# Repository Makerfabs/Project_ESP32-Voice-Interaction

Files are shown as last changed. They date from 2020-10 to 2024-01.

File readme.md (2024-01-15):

# ESP32 Voice Interaction

```c++
/*
Version:		V1.3
Author:			Vincent
Create Date:	2020/10/16

Note:
		2020/12/24 v1.3: Update readme.
		v1.2 Add Interphone example.
		v1.1 Add Record & Play example.
		
*/
```

[toc]

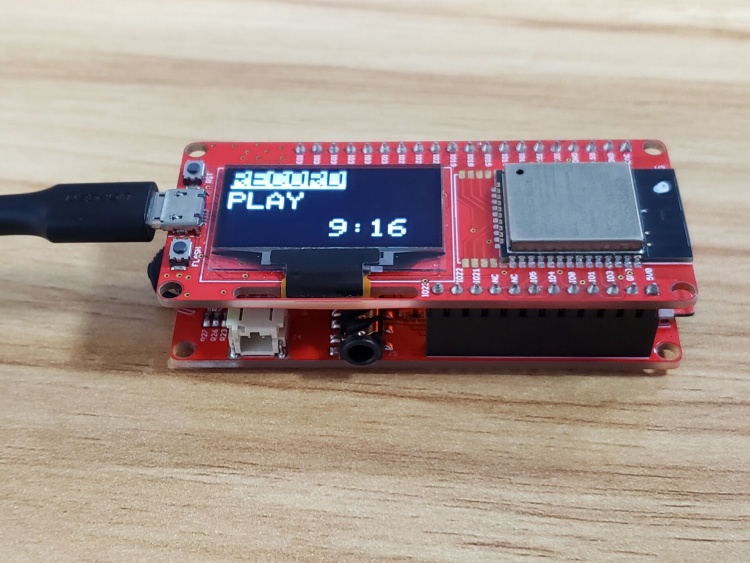
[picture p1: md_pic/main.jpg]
main


# Makerfabs

[Makerfabs home page](https://www.makerfabs.com/)

[Makerfabs Wiki](https://makerfabs.com/wiki/index.php?title=Main_Page)

# ESP32 Voice Interaction Hat

## Intruduce

Product Link ：[Voice Interaction Hat for Makepython](https://www.makerfabs.com/voice-interaction-hat-for-makepython.html) 

Wiki Link :  [Voice_Interaction_Hat_for_MakePython](https://wiki.makerfabs.com/Voice_Interaction_Hat_for_MaESP_ESP32.html) 

ESP32 Voice Interaction is an extended version with speakers and mics. The audio IC is WM8960. It has a button, SD card slot and a headphone jack.  It is convenient to produce MP3, interphone, recording pen and other items. 

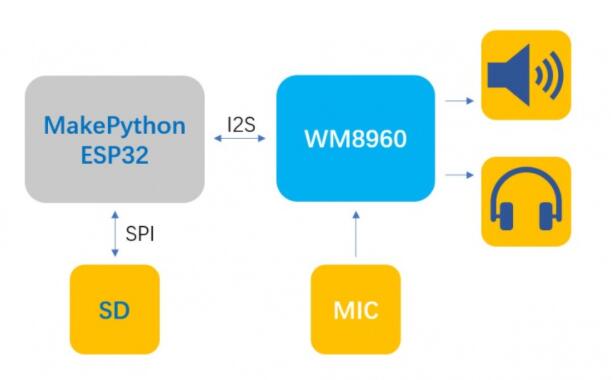
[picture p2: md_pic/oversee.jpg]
oversee


The two functions of recording pen and walkie-talkie are realized. The recorder pen provides a simple menu for selecting play and recording. A UDP walkie-talkie can talk to any device under the same WIFI.

## Feature

- Micro SD card slot on board.

### Front:

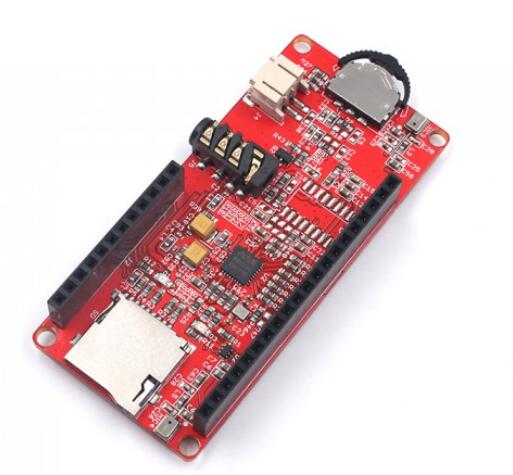
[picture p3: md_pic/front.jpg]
front


### Back:
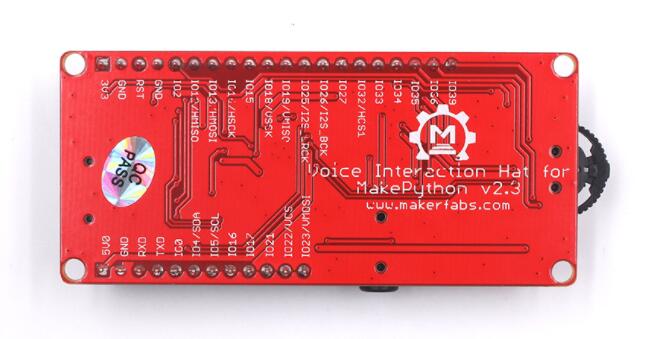
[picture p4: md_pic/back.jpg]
back


# Example

## Equipment list

- [MakePython ESP32](https://www.makerfabs.com/open-hardware/maboards/maesp.html)
- [MakaPython Voice Interaction Hat](https://www.makerfabs.com/voice-interaction-hat-for-makepython.html)
- Micro SD card (Part of the project)

## Compiler Options

**If you have any questions，such as how to install the development board, how to download the code, how to install the library. Please refer to :[Makerfabs_FAQ](https://github.com/Makerfabs/Makerfabs_FAQ)**

- Install board : ESP32 .
- Install library : Adafruit_GFX library.
- Install library : Adafruit SSD1306.

- Insert a Micro SD card into ESP32 Touch Camera.
- Upload codes, select "ESP32 Wrover Module" and "Huge APP"

## Example List

### ESP32_Record_Play
A recorder with a simple menu.

- Insert SD card.
- Upload code to ESP32.
- Restart ESP32.

### ESP32_Interphone
UDP protocol LAN walkie-talkie.

- Prepare two or more ESP32 and Voice Hat.
- Set WIFI ssid and password.
- Upload code to ESP32.
- Restart ESP32.
- Press the left button to speak, and others will play.

### wav_play
Test code, don't use. It can play wav file, but need a specific format.

### record
Record 5 second sound and playback.
- Insert SD card.
- Upload code to ESP32.
- Restart ESP32.
- Press the left button to start recording, recording will end at 5S.
- After the recording is over, the player will play the recording.

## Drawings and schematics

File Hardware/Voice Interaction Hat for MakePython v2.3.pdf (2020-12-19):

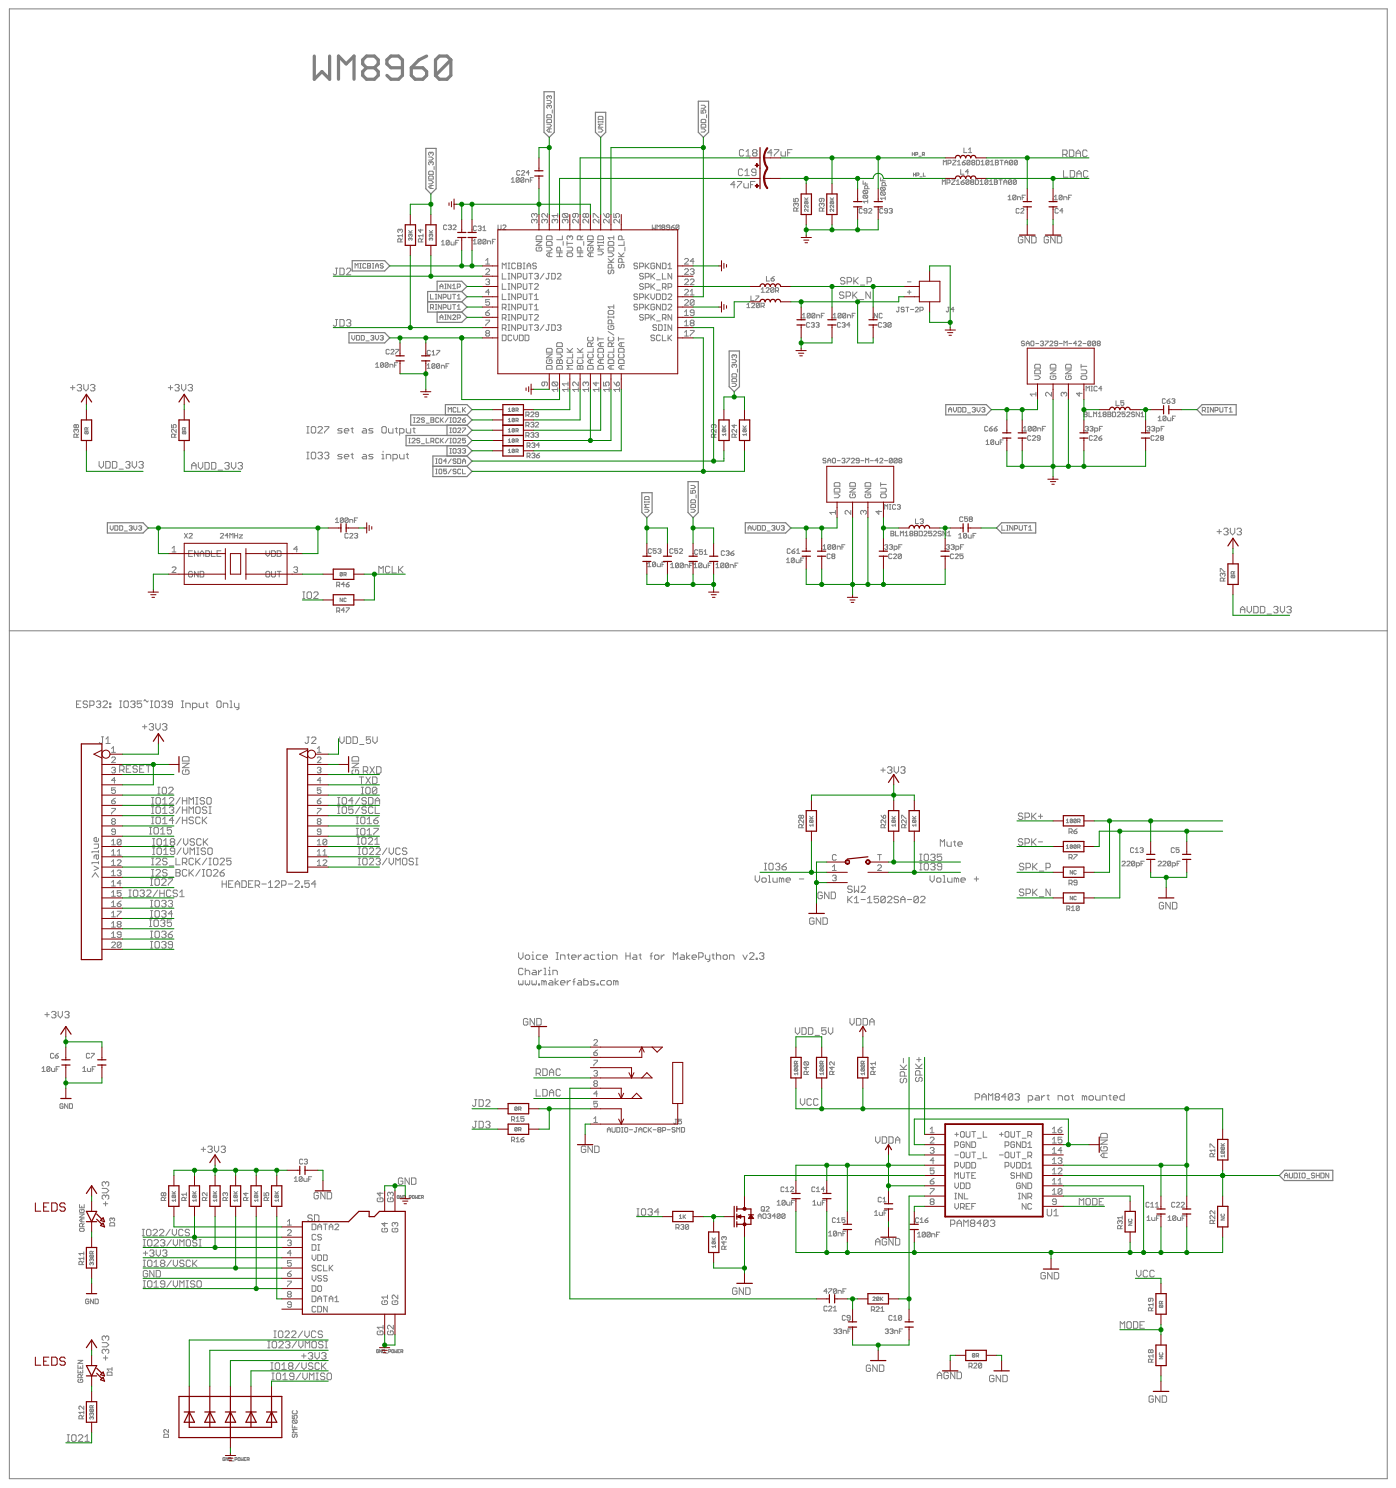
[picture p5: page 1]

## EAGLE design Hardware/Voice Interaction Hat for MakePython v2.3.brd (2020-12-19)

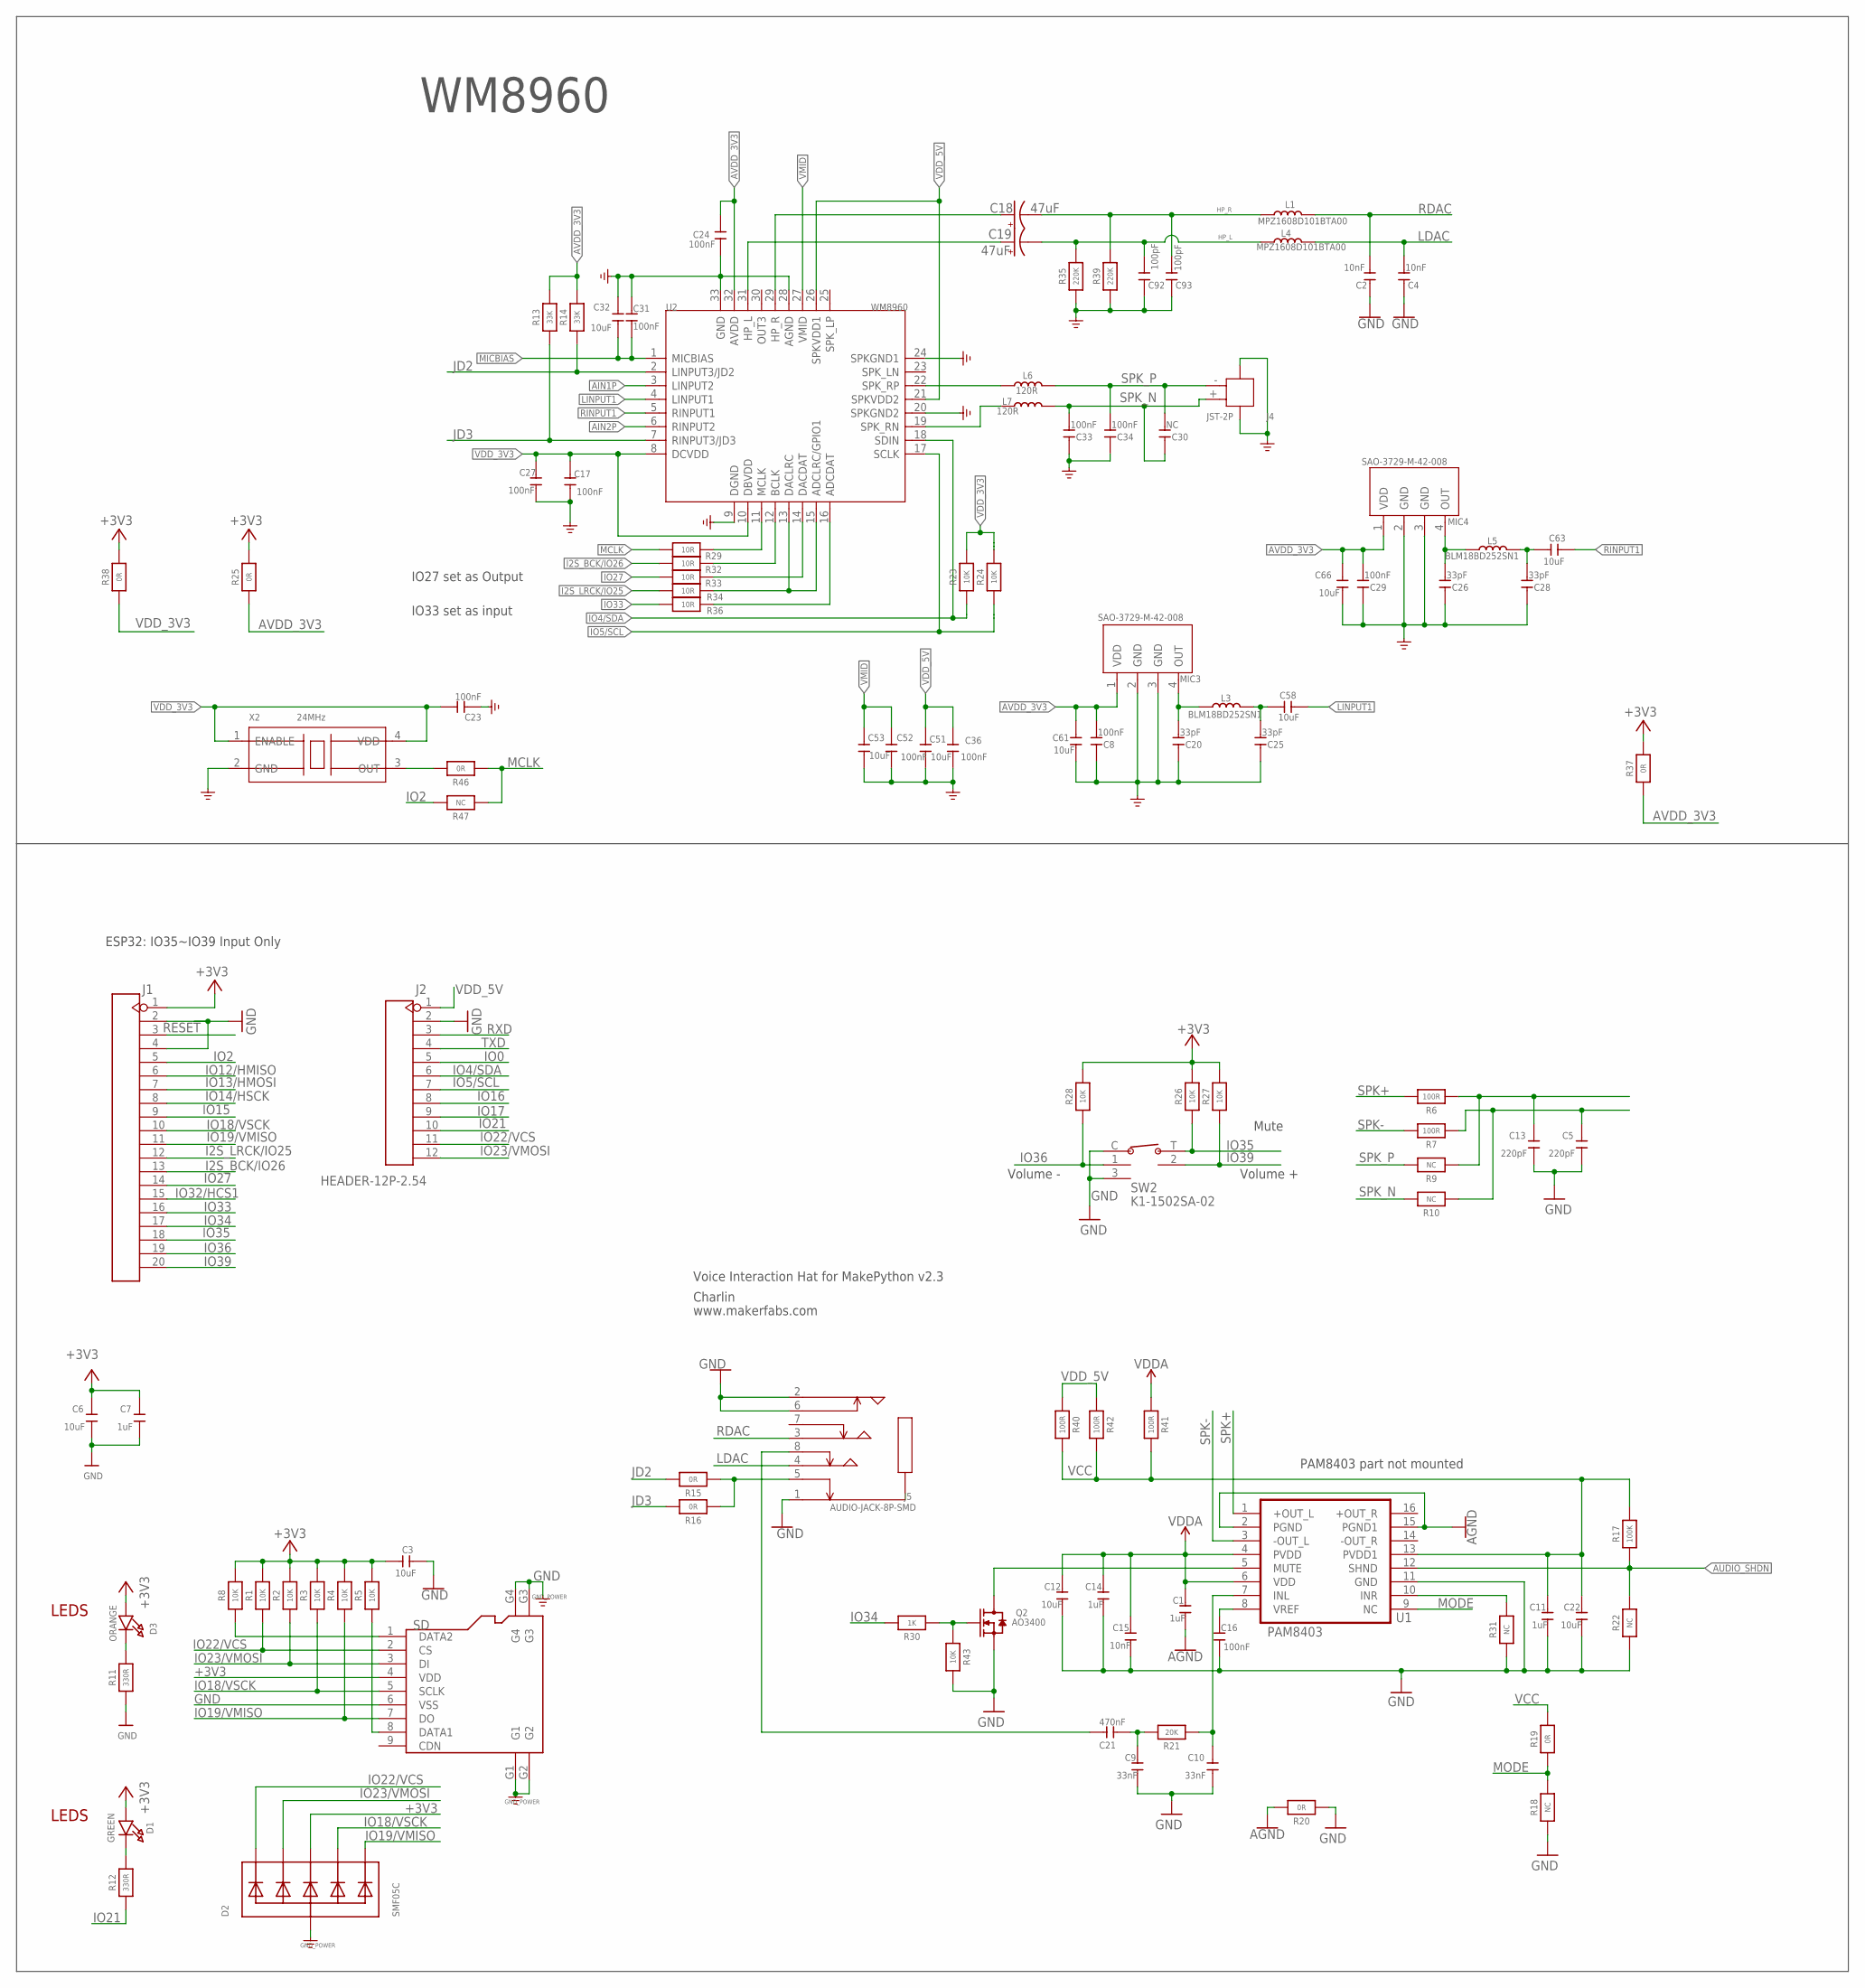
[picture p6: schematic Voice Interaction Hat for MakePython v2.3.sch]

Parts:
C1, C7, C11, C14: 1uF; DISCRETE_C0603
C2, C4: 10nF; C0402
C3, C6, C12, C22: 10uF; DISCRETE_C0603
C5, C13: 220pF; DISCRETE_C0603
C8, C29, C33, C34: 100nF; C0603
C9, C10: 33nF; DISCRETE_C0603
C15: 10nF; DISCRETE_C0603
C16: 100nF; DISCRETE_C0603
C17, C23, C24, C27, C31, C36, C52: 100nF; C0402
C18, C19: 47uF; EIA3528
C20, C25, C26, C28: 33pF; C0603
C21: 470nF; DISCRETE_C0603
C30: NC; C0603
C32, C51, C53, C58, C61, C63, C66: 10uF; C0603
C92, C93: 100pF; C0402
D1: GREEN; CHIPLED_0805_NOOUTLINE
D2: SMF05C; SOT363
D3: ORANGE; CHIPLED_0805_NOOUTLINE
J1: HEADER-20P-2.54; 20P-2.54
J2: HEADER-12P-2.54; 12P-2.54
J4: JST-2P; HW2-SMD-2.0-90D
J5: AUDIO-JACK-8P-SMD; AUDIO8P-SMD-3.5-14.5X6.1X4.0MM
L1, L4: MPZ1608D101BTA00; L0603
L3, L5: BLM18BD252SN1; L0603
L6, L7: 120R; L0603
MIC3, MIC4: SAO-3729-M-42-008; MIC4-SMD-3.76X2.95MM
Q2: AO3400; SOT23@1
R1, R2, R3, R4, R5, R8, R23, R24, R26, R27, R28, R43: 10K; 0603-NO
R6, R7, R40, R41, R42: 100R; 0603-NO
R9, R10, R18, R22, R31, R47: NC; 0603-NO
R11, R12: 330R; 0603-NO
R13, R14: 33K; 0603-NO
R15, R16, R19, R20, R25, R37, R38, R46: 0R; 0603-NO
R17: 100K; 0603-NO
R21: 20K; 0603-NO
R29, R32, R33, R34, R36: 10R; 0603-NO
R30: 1K; 0603-NO
R35, R39: 220K; 0603-NO
SD: HOLDER-MICROSD-9P; 9P-SMD-W/-RING
SW2: K1-1502SA-02; SMD5-60P-1180L1170W
U1: PAM8403; SOP-16
U2: WM8960; QFN32G-0.5-5X5MM
X2: 24MHz; OSC4-SMD-2.5X2.0X0.8MM

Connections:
$123: C18.A (+), U2.29 (HP_R)
$124: C19.A (+), U2.31 (HP_L)
+3V3: C3.2, C6.2, C7.2, D1.A, D2.4 (C3), D3.A, J1.1, R1.2, R2.2, R3.2, R4.2, R5.2, R8.2, R25.2, R26.2, R27.2, R28.2, R37.2, R38.2, SD.4 (VDD)
AGND: C1.1, R20.2, U1.2 (PGND), U1.15 (PGND1)
AIN1P: U2.3 (LINPUT2)
AIN2P: U2.6 (RINPUT2)
AUDIO_SHDN: R17.1, R22.2, U1.12 (SHND)
AVDD_3V3: C8.1, C24.2, C29.1, C61.2, C66.2, MIC3.1 (VDD), MIC4.1 (VDD), R13.2, R14.2, R25.1, R37.1, U2.32 (AVDD)
GND: C2.1, C3.1, C4.1, C5.1, C6.1, C7.1, C8.2, C9.1, C10.1, C11.1, C12.1, C13.1, C14.1, C15.1, C16.1, C17.1, C20.2, C22.1, C23.1, C24.1, C25.2, C26.2, C27.1, C28.2, C29.2, C31.2, C32.1, C33.2, C34.2, C36.1, C51.2, C52.1, C53.2, C61.1, C66.1, C92.1, C93.1, D2.2 (A), J1.2, J1.4, J2.2, J4.3, J4.4, J5.1, J5.2, J5.6, MIC3.2 (GND), MIC3.3 (GND), MIC4.2 (GND), MIC4.3 (GND), Q2.2 (S), R11.1, R18.1, R20.1, R22.1, R31.1, R35.1, R39.1, R43.2, SD.6 (VSS), SD.G1, SD.G2, SD.G3, SD.G4, SW2.3, SW2.C, U1.11 (GND), U2.9 (DGND), U2.20 (SPKGND2), U2.24 (SPKGND1), U2.28 (AGND), U2.33 (GND), X2.2 (GND)
HP_L: C19.C (-), C92.2, L4.1, R35.2
HP_R: C18.C (-), C93.2, L1.1, R39.2
I2S_BCK/IO26: J1.13, R32.2
I2S_LRCK/IO25: J1.12, R34.2
IO0: J2.5
IO2: J1.5, R47.2
IO4/SDA: J2.6, R23.1, U2.18 (SDIN)
IO5/SCL: J2.7, R24.1, U2.17 (SCLK)
IO12/HMISO: J1.6
IO13/HMOSI: J1.7
IO14/HSCK: J1.8
IO15: J1.9
IO16: J2.8
IO17: J2.9
IO18/VSCK: D2.5 (C4), J1.10, R3.1, SD.5 (SCLK)
IO19/VMISO: D2.6 (C5), J1.11, R4.1, SD.7 (DO)
IO21: J2.10, R12.1
IO22/VCS: D2.1 (C1), J2.11, R1.1, SD.2 (CS)
IO23/VMOSI: D2.3 (C2), J2.12, R2.1, SD.3 (DI)
IO27: J1.14, R33.2
IO32/HCS1: J1.15
IO33: J1.16, R36.2
IO34: J1.17, R30.2
IO35: J1.18, R26.1, SW2.T
IO36: J1.19, R28.1, SW2.1
IO39: J1.20, R27.1, SW2.2
JD2: R14.1, R15.2, U2.2 (LINPUT3/JD2)
JD3: R13.1, R16.2, U2.7 (RINPUT3/JD3)
LDAC: C4.2, J5.4, L4.2
LINPUT1: C58.2, U2.4 (LINPUT1)
MCLK: R29.2, R46.1, R47.1
MICBIAS: C31.1, C32.2, U2.1 (MICBIAS)
MODE: R18.2, R19.1, U1.9 (NC)
unnamed: R8.1, SD.1 (DATA2)
unnamed: R5.1, SD.8 (DATA1)
unnamed: D1.C, R12.2
unnamed: C10.2, R21.1, U1.7 (INL)
unnamed: D3.C, R11.2
unnamed: C13.2, R6.1, R9.1
unnamed: C9.2, C21.1, R21.2
unnamed: Q2.1 (G), R30.1, R43.1
unnamed: J5.5, R15.1, R16.1
unnamed: R33.1, U2.14 (DACDAT)
unnamed: Q2.3 (D), U1.5 (MUTE)
unnamed: C25.1, C58.1, L3.2
unnamed: C20.1, L3.1, MIC3.4 (OUT)
unnamed: C5.2, R7.1, R10.1
unnamed: C28.1, C63.1, L5.2
unnamed: C16.2, U1.8 (VREF)
unnamed: R46.2, X2.3 (OUT)
unnamed: R31.2, U1.10 (INR)
unnamed: C26.1, L5.1, MIC4.4 (OUT)
unnamed: R36.1, U2.16 (ADCDAT)
unnamed: R34.1, U2.13 (DACLRC), U2.15 (ADCLRC/GPIO1)
unnamed: R32.1, U2.12 (BCLK)
unnamed: R29.1, U2.11 (MCLK)
unnamed: L6.1, U2.22 (SPK_RP)
unnamed: L7.1, U2.19 (SPK_RN)
unnamed: C21.2, J5.8
RDAC: C2.2, J5.3, L1.2
RESET: J1.3
RINPUT1: C63.2, U2.5 (RINPUT1)
RXD: J2.3
SPK+: R6.2, U1.1 (+OUT_L)
SPK-: R7.2, U1.3 (-OUT_L)
SPK_N: C30.2, C33.1, J4.+ (1), L7.2, R10.2
SPK_P: C30.1, C34.1, J4.- (2), L6.2, R9.2
TXD: J2.4
VCC: C11.2, C22.2, R17.2, R19.2, R40.2, R41.2, R42.2, U1.13 (PVDD1)
VDDA: C1.2, C12.2, C14.2, C15.2, R41.1, U1.4 (PVDD), U1.6 (VDD)
VDD_3V3: C17.2, C23.2, C27.2, R23.2, R24.2, R38.1, U2.8 (DCVDD), U2.10 (DBVDD), X2.1 (ENABLE), X2.4 (VDD)
VDD_5V: C36.2, C51.1, J2.1, R40.1, R42.1, U2.21 (SPKVDD2), U2.26 (SPKVDD1)
VMID: C52.2, C53.1, U2.27 (VMID)

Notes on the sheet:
ESP32: IO35~IO39 Input Only
Voice Interaction Hat for MakePython v2.3
LEDS
Charlin
Volume +
Volume -
Mute
www.makerfabs.com
WM8960
IO27 set as Output
IO33 set as input
PAM8403 part not mounted

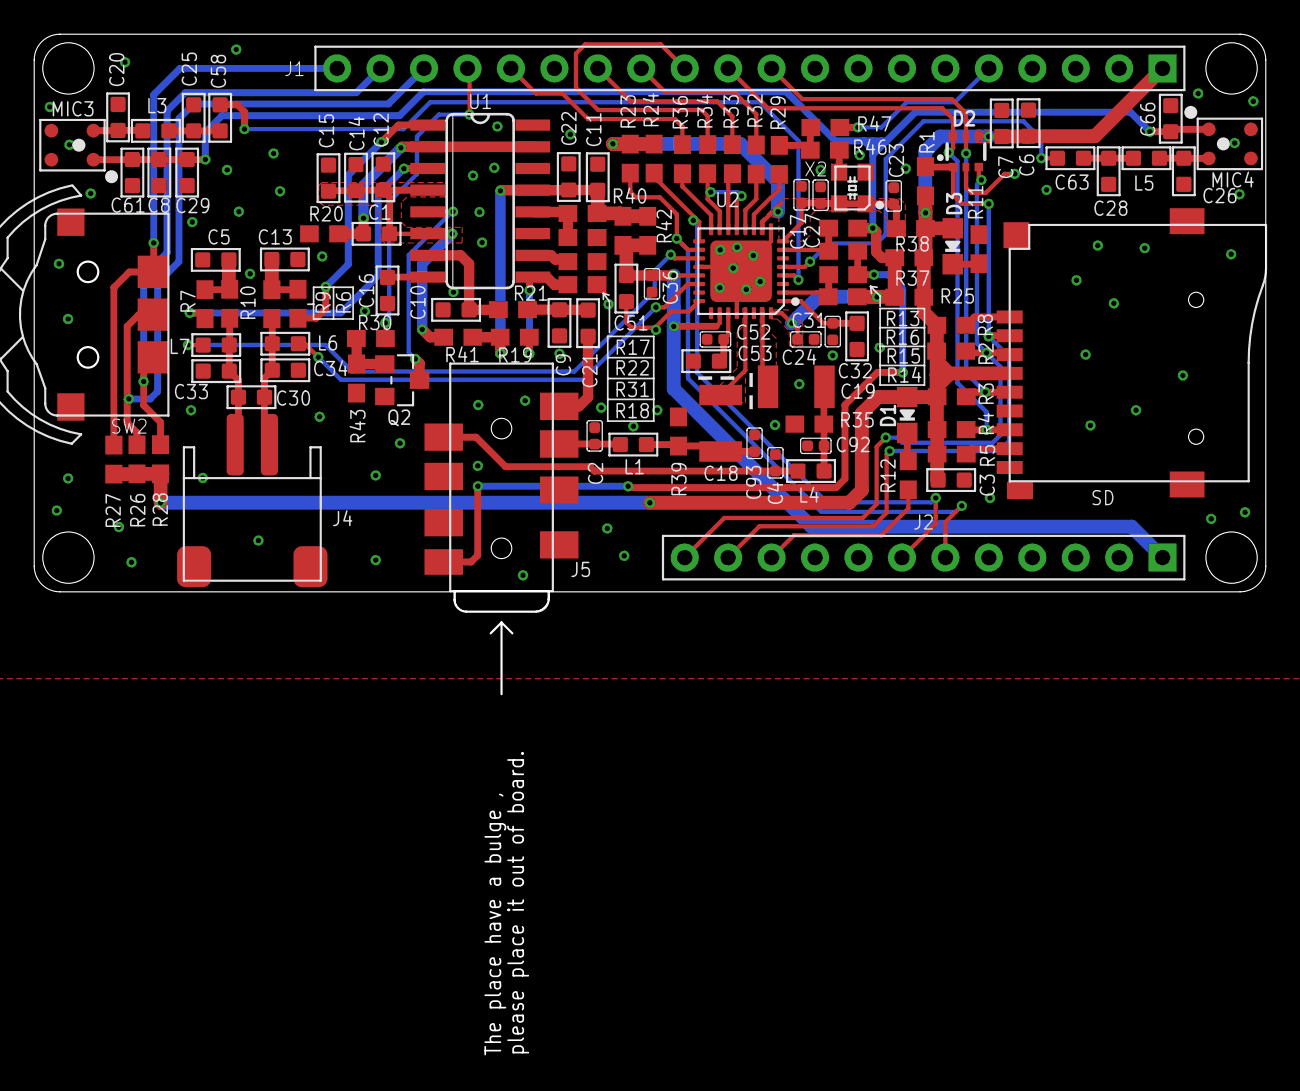
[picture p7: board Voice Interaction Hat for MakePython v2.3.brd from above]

Board: 2 copper layers, 72.0 x 32.6 mm, 111 parts (1 on the bottom side), 69 nets.

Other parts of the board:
U$1: MAKERFABS_0.3

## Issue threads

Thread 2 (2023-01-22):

Running ESP32_Record_Play at 44100 issue

thanks-for-your-help, 2023-01-22:
Hello,

I'm trying to get this code to work at 44100 instead of 16000.

In I2S.H I commented out 16000 and uncommented 44100.

In wav.cpp, I commented headers 24 and 25 to 16000 and uncommented headers 24 and 25 to 44100. I also commented headers 28 to 31 to 16000 and uncommented headers 28 to 31 to 44100.

In ESP32_Record_Play.ino, I replaced:

int waveDataSize = record_time * 16000 * 16 * 2 / 8;

through

int waveDataSize = record_time * 44100 * 16 * 2 / 8;

Unfortunately that doesn't work.

What have I forgotten?

Can you provide a 44100 / 48000 version.

Thanks in advance.

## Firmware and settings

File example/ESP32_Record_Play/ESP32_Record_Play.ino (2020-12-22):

#include <WiFi.h>
#include <FS.h>
#include <SD.h>
#include <SPI.h>
#include <Wire.h>
#include "wm8960.h"
#include "makerfabs_pin.h"
#include <Adafruit_GFX.h>
#include <Adafruit_SSD1306.h>
#include "time.h"

#define V1  39
#define V2  36
#define mute 35

//Voice
const int record_time = 1; // second
String filename = "/textsound.wav";

char i2s_buffer[64000];

int log_index = 0;

String file_list[20];
int file_num = 0;
int file_index = 0;


//LCD

Adafruit_SSD1306 display(MP_ESP32_SSD1306_WIDTH, MP_ESP32_SSD1306_HEIGHT, &Wire, MP_ESP32_SSD1306_RST);


//WIFI
const char *ssid = "Makerfabs";
const char *password = "20160704";

//NTP time
//const char* ntpServer = "pool.ntp.org";
const char *ntpServer = "120.25.108.11";
const long gmtOffset_sec = 8 * 60 * 60; //China+8
const int daylightOffset_sec = 0;

struct tm timeinfo;

void setup()
{
    uint8_t res;

    //LCD
    Wire.begin(MP_ESP32_I2C_SDA, MP_ESP32_I2C_SCL);
    // SSD1306_SWITCHCAPVCC = generate display voltage from 3.3V internally
    if (!display.begin(SSD1306_SWITCHCAPVCC, 0x3C))
    { // Address 0x3C for 128x32
        Serial.println(F("SSD1306 allocation failed"));
        for (;;)
            ; // Don't proceed, loop forever
    }

    display.clearDisplay();
    logoshow();
    Serial.begin(115200);

    pinMode ( V1 , INPUT);
    pinMode ( V2 , INPUT);
    pinMode ( mute, INPUT);
    
    res = WM8960_Init(MP_VOICE_I2S_DIN, MP_VOICE_I2S_DOUT, MP_VOICE_I2S_LRC, MP_VOICE_I2S_BCLK);
    if (res != 0)
        Serial.println(res);

    //SD(SPI)
    pinMode(MP_VOICE_SD_CS, OUTPUT);
    digitalWrite(MP_VOICE_SD_CS, HIGH);
    SPI.begin(MP_VOICE_SPI_SCK, MP_VOICE_SPI_MISO, MP_VOICE_SPI_MOSI);
    SPI.setFrequency(1000000);
    if (!SD.begin(MP_VOICE_SD_CS, SPI))
    {
        Serial.println("Card Mount Failed");
        while (1)
            ;
    }
    
    //remove_soundwav_file(SD, "/");

        //connect to WiFi
    Serial.printf("Connecting to %s ", ssid);
    WiFi.begin(ssid, password);
    while (WiFi.status() != WL_CONNECTED)
    {
        delay(500);
        Serial.print(".");
    }
    Serial.println(" CONNECTED");

    //time
    configTime(gmtOffset_sec, daylightOffset_sec, ntpServer);
    Serial.println(F("Alread get npt time."));


    
    //Changefilename(); 

    //WM8960_Volume(0.8,0.8);
    WM8960_Volume(1.0,1.0);
    //WM8960_Volume(0.0,0.0);

    //recode
    //SD.remove(filename);

    //WM8960_Record(filename, i2s_buffer, record_time);

    //WM8960_Play(filename, i2s_buffer);

    //WM8960_Alarm();
}



int m0 = 1;
int t0;

void loop()
{
    if (!getLocalTime(&timeinfo))
        Serial.println("Failed to obtain time");


  
    int enter = digitalRead(mute) ;
    int play1 = digitalRead (V1);
    int play2 = digitalRead (V2);
    switch (m0)
    {
      case 1: displaymenu(1); break;
      case 2: displaymenu(2); break;
    }
    if ( play1 == 0 && m0 != 0)
    {
      m0--;
      if (m0>2) m0=1;
      delay(300);
    }

    if ( play2 == 0 && m0 !=0 )
    {
      m0++;
      if (m0<1) m0=2;
      delay(300);
    }
    
    if( enter ==0 )
    {
      t0 = m0;
/**************** play ***********************/      
      if( t0 == 2)
      { 
        m0 = 0;
        playmenu();       
         delay(500);
         m0 = 1;

       }
/************ record **********************/
       if( t0 == 1)
       {

            Changefilename();
            displayrecording(1);
            WM8960_Record(filename, i2s_buffer, record_time);
            //delay(500);
          //Changefilename(); 
         displayrecording(2);
       }
    }
    
    
   
}

void logoshow(void)
{
    display.clearDisplay();

    display.setTextSize(2);              // Normal 1:1 pixel scale
    display.setTextColor(SSD1306_WHITE); // Draw white text
    display.setCursor(0, 0);             // Start at top-left corner
    display.println(F("MakePython"));
    display.setCursor(0, 20); // Start at top-left corner
    display.println(F("Voice"));
    display.display();
    delay(2000);
}

void displayrecording(int t)
{
    display.clearDisplay();            
    display.setTextColor(SSD1306_WHITE); // Draw white text    
    display.setCursor(0, 40); // Start at top-left corner
    display.setTextSize(1);
    if ( t==1)
    {
      //display.println(F("Recording..."));
    }
    else
      display.println(F("Recording completed"));
    display.display();
    delay(100);
}

void displaying(int t)
{
    
    display.clearDisplay();         
    display.setTextColor(SSD1306_WHITE); // Draw white text    
    display.setCursor(0, 40); // Start at top-left corner
    display.setTextSize(1);
    if ( t==1)
    {
      display.setCursor(0, 0); // Start at top-left corner
      display.setTextSize(1);
      display.setTextColor(SSD1306_BLACK,SSD1306_WHITE);
      display.println(file_list[file_num-1]);
      display.setCursor(0, 20);
      display.setTextColor(SSD1306_WHITE); 
      display.println(file_list[file_num-2]);
      display.setCursor(0, 40);
      display.println("EXIT");
    }
    else if ( t==2 )
    {
      display.setCursor(0, 0); // Start at top-left corner
      display.setTextSize(1);
      display.setTextColor(SSD1306_WHITE);
      display.println(file_list[file_num-1]);
      display.setCursor(0, 20);
      display.setTextColor(SSD1306_BLACK,SSD1306_WHITE); 
      display.println(file_list[file_num-2]);
      display.setCursor(0, 40);
      display.setTextColor(SSD1306_WHITE); 
      display.println("EXIT");

    }
    else 
    {
      display.setCursor(0, 0); // Start at top-left corner
      display.setTextSize(1);
      display.setTextColor(SSD1306_WHITE);
      display.println(file_list[file_num-1]);
      display.setCursor(0, 20);
      display.setTextColor(SSD1306_WHITE); 
      display.println(file_list[file_num-2]);
      display.setCursor(0, 40);
      display.setTextColor(SSD1306_BLACK,SSD1306_WHITE); 
      display.println("EXIT");
    }
    display.display();  
}

void displaymenu(int t)
{
    display.clearDisplay();
    int hour = timeinfo.tm_hour;
    int min = timeinfo.tm_min;
    
    String displaytime = String(hour) + ":" + String(min);
    display.setTextSize(2);              // Normal 1:1 pixel scale
    if ( t==1)
    {
      display.setTextColor(SSD1306_BLACK,SSD1306_WHITE); // Draw white text    
      display.setCursor(0, 0); // Start at top-left corner
      display.println(F("RECORD"));
      display.setTextColor(SSD1306_WHITE); // Draw white text    
      display.setCursor(0, 20);
      display.println(F("PLAY"));
      display.setCursor(64, 44);
      display.println(displaytime);
      
      
    }
    else
    {
      display.setTextColor(SSD1306_WHITE); // Draw white text    
      display.setCursor(0, 0); // Start at top-left corner
      display.println(F("RECORD"));
      display.setTextColor(SSD1306_BLACK,SSD1306_WHITE); // Draw white text    
      display.setCursor(0, 20);
      display.println(F("PLAY"));
      display.setTextColor(SSD1306_WHITE);
      display.setCursor(64, 44);
      display.println(displaytime);
    }
    display.display();
    //delay(2000);
}

void Changefilename()
{
    int hour = timeinfo.tm_hour;
    int min = timeinfo.tm_min;
    int day = timeinfo.tm_mday;
    int mon = timeinfo.tm_mon + 1;
    filename = "/" + String(mon) + String(day) + String(hour) + String(min) + "v.wav";

    
}

void WM8960_Record(String filename, char *buff, int record_time)
{
    int headerSize = 44;
    byte header[headerSize];
    int waveDataSize = record_time * 16000 * 16 * 2 / 8;
    int waveDataSize1  = waveDataSize;
    int recode_time = millis();
    int part_time = recode_time;

    File file = SD.open(filename, FILE_WRITE);
    if (!file)
        return;

    Serial.println("Begin to record:");
    //CreateWavHeader(header, waveDataSize);
    //file.write(header, headerSize);
    
    int enter1 = digitalRead(mute) ;
    int t = 0;
    while (enter1 == 0){
      display.clearDisplay(); 
      display.setTextSize(2); 
      display.setCursor(40, 20);
      display.setTextColor(SSD1306_WHITE);
      display.print(t+1);
      display.println(F("s"));
      display.setCursor(0, 40);
      display.setTextSize(1);
      display.println(F("Recording..."));
      display.display(); 
    for (int j = 0; j < waveDataSize / sizeof(buff); ++j)
    {
        I2S_Read(buff, sizeof(buff));
        file.write((const byte *)buff, sizeof(buff));
        if ((millis() - part_time) > 1000)
        {
            Serial.print(".");
            part_time = millis();
        }
    }
      t++;
      enter1 = digitalRead(mute) ;
    }
    waveDataSize1 = waveDataSize1 * t;
    file.seek(0);
    CreateWavHeader(header, waveDataSize1);
    file.write(header, headerSize);
    
    Serial.println("");
    Serial.println("Finish");
    Serial.println(millis() - recode_time);
    file.close();
}

void playmenu()
{ 
    file_num = get_music_list(SD, "/", 0, file_list);
    int m2 = 1;
    while(m2 != 0)
    {

        switch(m2)
          {
              case 1: displaying(1); break;
              case 2: displaying(2); break;
              case 3: displaying(3) ; break;
             }

        int enter = digitalRead(mute) ;
        int play1 = digitalRead (V1);
        int play2 = digitalRead (V2);
        if ( play1 == 0 && t0 == 2)
        {
            m2--;
            if (m2>3) m2=1;
            delay(300);
        }

        if ( play2 == 0 && t0 ==2 )
        {
            m2++;
            if (m2<1) m2=3;
            delay(300);
        }
    
        if( enter ==0 && t0 == 2)
        {   
          switch(m2)
          {
              case 1: {playsounding(); WM8960_Play(file_list[file_num-1], i2s_buffer); } break;
              case 2: {playsounding(); WM8960_Play(file_list[file_num-2], i2s_buffer); } break;
              case 3: m2=0 ; break;
             }
          delay(300);
         }     
    }
   Serial.printf("menu m2 exit"); 
}

int get_music_list(fs::FS &fs, const char *dirname, uint8_t levels, String wavlist[30])
{
    Serial.printf("Listing directory: %s\n", dirname);
    int i = 0;

    File root = fs.open(dirname);
    if (!root)
    {
        Serial.println("Failed to open directory");
        return i;
    }
    if (!root.isDirectory())
    {
        Serial.println("Not a directory");
        return i;
    }

    File file = root.openNextFile();
    while (file)
    {
        if (file.isDirectory())
        {
        }
        else
        {
            String temp = file.name();
            if (temp.endsWith(".wav"))
            {
                wavlist[i] = temp;
                i++;
            }
            
        }
        file = root.openNextFile();
    }
    file.close();
    return i;
}
/*
void remove_soundwav_file(fs::FS &fs, const char *dirname)
{
    Serial.printf("remove:");


    File root = fs.open(dirname);
    if (!root)
    {
        Serial.println("Failed to open directory");
        
    }
    if (!root.isDirectory())
    {
        Serial.println("Not a directory");
        
    }

    File file = root.openNextFile();
    while (file)
    {
        if (file.isDirectory())
        {
        }
        else
        {
            String temp = file.name();
            if (temp.endsWith("sound.wav"))
            {
                fs.remove(temp);
               
            }
            
        }
        file = root.openNextFile();
    }
    file.close();
 
}
*/
void playsounding()
{
   
    display.clearDisplay();
    display.setTextSize(2);              // Normal 1:1 pixel scale

      display.setTextColor(SSD1306_BLACK,SSD1306_WHITE); // Draw white text    
      display.setCursor(0, 20); // Start at top-left corner
      display.println(F("Playing..."));
    display.display();

}

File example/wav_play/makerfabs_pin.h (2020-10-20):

/*
-------------------------------------------------
titile  :   Makerfabs IO define
author  :   Vincent
create  :   2020/9/4
version :   1.3
update  :   2020/9/29

Note:
    v1.0 : Create Project.
    v1.1 : Add MakePython Audio support.
    v1.2 : Ass MakePython A9G support.
    v1.3 : Add A9G and ILI9341 support.

1.
For easy use ESP32 GPIO,define SPI, I2C, and LCD, SDcard pins.
And define some parameters, such as screen size.

2.
Sigillum:
MP = MakePython
MP_ESP32 = MakePython ESP32 SSD1306
MP_ESP32_COLOR = MakePython ESP32 Color LCD (ST7789)

TSC = Touch Screen Camera
ESP32_TSC_9488 = ESP32 Touch Screen Camera With ILI9488

3.
//#define ESP32_COLOR_7789 OK
"Ok" means tested and ready to use
Don't use "ERR" or "TEST"

4.
For the motherboard combination expansion board.
This is to be determined and may be modified.
A more prudent approach is to copy the pin value directly.

-------------------------------------------------
Support List:

    (1)MakePython:
        MakePython ESP32 COLOR LCD
        MakePython ESP32 SSD1306
        MakePython Audio
        MakePython A9G

    (2)Touch Screen Camera:
        ESP32 Touch Screen Camera With 9488
        ESP32 Touch Screen Camera With ILI9341

-------------------------------------------------
*/

//BOARD

#define MP_ESP32 OK
//#define MP_ESP32_COLOR OK
//#define ESP32_TSC_9488 OK
//#define ESP32_TSC_9341 OK 

//SHIELD
//#define MP_AUDIO OK
//#define MP_A9G OK
#define MP_VOICE TEST

//******************************************************************************

/*
update  :   2020/9/8
name    :   MakePython ESP32 SSD1306
sigillum:   MP_ESP32_COLOR
wiki    :   https://www.makerfabs.com/wiki/index.php?title=MakePython_ESP32
module  :   
            (1) 1.3inch OLED SSD1306

*/
#ifdef MP_ESP32

#define MP_ESP32_FLASH_BUTTON 0

//I2C
#define MP_ESP32_I2C_SDA 4
#define MP_ESP32_I2C_SCL 5

//HSPI
#define MP_ESP32_HSPI_MOSI 13
#define MP_ESP32_HSPI_MISO 12
#define MP_ESP32_HSPI_SCK 14
#define MP_ESP32_HSPI_CS 15

//VSPI
#define MP_ESP32_VSPI_MOSI 23
#define MP_ESP32_VSPI_MISO 19
#define MP_ESP32_VSPI_SCK 18
#define MP_ESP32_VSPI_CS 5

//SSD1306
#define MP_ESP32_SSD1306_I2C_ADDR 0x3C
#define MP_ESP32_SSD1306_WIDTH 128 // OLED display width, in pixels
#define MP_ESP32_SSD1306_HEIGHT 64 // OLED display height, in pixels
#define MP_ESP32_SSD1306_RST -1

#endif

/*
update  :   2020/9/11
name    :   MakePython ESP32 COLOR LCD
sigillum:   MP_ESP32_COLOR
wiki    :   https://www.makerfabs.com/wiki/index.php?title=MakePython_ESP32_Color_LCD
module  :   
            (1) 1.3inch TFT ST7789 driver

*/
#ifdef MP_ESP32_COLOR

//I2C
#define MP_ESP32_COLOR_I2C_SDA 4
#define MP_ESP32_COLOR_I2C_SCL 5

//HSPI
#define MP_ESP32_COLOR_HSPI_MOSI 13
#define MP_ESP32_COLOR_HSPI_MISO 12
#define MP_ESP32_COLOR_HSPI_SCK 14
#define MP_ESP32_COLOR_HSPI_CS 15

//VSPI
#define MP_ESP32_COLOR_VSPI_MOSI 23
#define MP_ESP32_COLOR_VSPI_MISO 19
#define MP_ESP32_COLOR_VSPI_SCK 18
#define MP_ESP32_COLOR_VSPI_CS 5

//ST7789
#define MP_ESP32_COLOR_LCD_MOSI MP_ESP32_COLOR_HSPI_MOSI
#define MP_ESP32_COLOR_LCD_MISO MP_ESP32_COLOR_HSPI_MISO
#define MP_ESP32_COLOR_LCD_SCK MP_ESP32_COLOR_HSPI_SCK

#define MP_ESP32_COLOR_LCD_CS 15

#define MP_ESP32_COLOR_LCD_RST 21
#define MP_ESP32_COLOR_LCD_DC 22
#define MP_ESP32_COLOR_LCD_BL -1 //5

#define MP_ESP32_COLOR_LCD_WIDTH 240
#define MP_ESP32_COLOR_LCD_HEIGHT 240
#define MP_ESP32_COLOR_LCD_SPI_HOST HSPI_HOST

#endif

/*
update  :   2020/9/22
name    :   ESP32 Touch Screen Camera With ILI9488
sigillum:   ESP32_TSC_9488 
wiki    :   
module  :   
            (1) 3.5inch TFT ILI9488 driver
            (2) SDcard Reader
            (3) I2C Touch Screen(NS2009 or Ft6236)
            (4) OV2640 Camera
note    :
            (1) In camera need VSPI, but actually use HSPI. Why?
*/

#ifdef ESP32_TSC_9488

//I2C
#define ESP32_TSC_9488_I2C_SDA 26
#define ESP32_TSC_9488_I2C_SCL 27

//SPI
#define ESP32_TSC_9488_HSPI_MOSI 13
#define ESP32_TSC_9488_HSPI_MISO 12
#define ESP32_TSC_9488_HSPI_SCK 14
#define ESP32_TSC_9488_HSPI_CS 15

//ILI9488
#define ESP32_TSC_9488_LCD_MOSI ESP32_TSC_9488_HSPI_MOSI
#define ESP32_TSC_9488_LCD_MISO ESP32_TSC_9488_HSPI_MISO
#define ESP32_TSC_9488_LCD_SCK ESP32_TSC_9488_HSPI_SCK

#define ESP32_TSC_9488_LCD_CS 15

#define ESP32_TSC_9488_LCD_RST 26
#define ESP32_TSC_9488_LCD_DC 33
#define ESP32_TSC_9488_LCD_BL -1

#define ESP32_TSC_9488_LCD_WIDTH 320
#define ESP32_TSC_9488_LCD_HEIGHT 480
#define ESP32_TSC_9488_LCD_SPI_HOST VSPI_HOST   //?? IF use HSPI, will wrong.

//SDcard
#define ESP32_TSC_9488_SD_MOSI ESP32_TSC_9488_HSPI_MOSI
#define ESP32_TSC_9488_SD_MISO ESP32_TSC_9488_HSPI_MISO
#define ESP32_TSC_9488_SD_SCK ESP32_TSC_9488_HSPI_SCK

#define ESP32_TSC_9488_SD_CS 4

#endif

/*
update  :   2020/9/29
name    :   ESP32 Touch Screen Camera With ILI9341
sigillum:   ESP32_TSC_9341 
wiki    :   
module  :   
            (1) 3.2inch TFT ILI9341 driver
            (2) SDcard Reader
            (3) SPI Touch Screen(STMPE610)
            (4) OV2640 Camera
*/
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

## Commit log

2020-12-19 V2.3
    Schematic and PCB
    [Voice Interaction Hat for MakePython v2.3.brd, Voice Interaction Hat for MakePython v2.3.sch]
2020-12-24 Change wrong directory name
    [I2S.h, makerfabs_pin.h, wav_play.ino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]

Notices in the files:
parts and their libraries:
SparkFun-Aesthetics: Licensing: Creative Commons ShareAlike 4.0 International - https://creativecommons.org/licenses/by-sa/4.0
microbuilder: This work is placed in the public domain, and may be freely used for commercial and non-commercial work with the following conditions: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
